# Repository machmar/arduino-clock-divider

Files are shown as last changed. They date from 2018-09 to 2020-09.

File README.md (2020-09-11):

# arduino-clock-divider
A clock divider that uses a arduino. It divides by 1; 2; 3; 4; 5; 6; 7; 8; 9 and 10.
```
Animations: (only some versions have this feature - the 1.1.1 and 1.4.1 dont have it for sure and Im not sure about the other versions)
       1.Activate them by unplugging the clock source.
       2.Use the divide by 10 as a clock input for animations.
       3.To select animations, Send a trigger to the divide by 9 pin.
       4.All of the animations are displayed on the divide by 1 to 8 leds
       5.Even thought it is displaying animations, it is still sending gates.
       6.To get back to dividing, just plug the clock jack back in.
```
THIS DIVIDER WILL NOT WORK WITH STEREO CABLES, as it relies on the fact that the mono jack shorts the second terminal of the stereo jack to ground. So If you want to make it work with stereo cables, than you have to connect the second contact to ground on the other side of the cable.

TO MAKE THIS WORK WITH STEREO CABLES, you just need to connect pin A0 to ground. That way the arduino will think you have a jack connected all the time, thus not deploing any animations at all. A optional thing you can do is to add a switch to the A0 that swithecs between 5 and 0 Volts.

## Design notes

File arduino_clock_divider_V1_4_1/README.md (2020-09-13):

So here it is. Im actually going throught my modules and fixing them.

This update adds new functionality while still keeping some of the old stuff. 
As in previous versions, plug a cable into the input to select Division mode. Leave the socket empty to select logic mode.
```
Division mode can be further adjusted with the expander (NOT TESTED WITH THIS VERSION) or the jumpers on the back.
Jumpers: 
  prime - 
      unconnected - the module divides by 1, 2, 3, 4, 5, 6, 7, 8, 9, 10
      connected   - the module divides by 1, 2, 3, 5, 7, 11, 13, 17, 19, 23
  serial - !NEVER CONNECT TOGETHER!
  edge - 
      unconnected - the module reacts both to the falling and rising edge of the clock input
      connected   - the module reacts to only the rising edge of the clock input
  g/t -
      unconnected - the module will output a gate signal    - once the division number is reached, 
                    the output state will invert
      connected   - the module will output a trigger signal - once the division number is reached, 
                    the output state will be set to high to a small ammount of time, after which 
                    it will be set back to low
  rst/10 - 
      unconnected - the module will use its "divide by 10" output as a standard output
      connected   - the module will use its "divide by 10" output as a trigger input - when this 
                    output recievs a high signal, it will reset all division counters and set 
                    all outputs to low
  leds - 
      unconnected - the LEDs behind the panel will not be refreshed and thus the module will run faster
      connected   - the LEDs behind the panel will be refreshed and thus the module will run slower but look better
      
Logic mode can not be adjusted with any jumpers - those are exclusive for division mode
  In logic mode, the outputs 1, 2, 9, 10 become inputs and the outputs 3, 4, 5, 6, 7, 8 become 
  outputs of logic operations controlled by the four inputs.
  
  In the code the inputs 1 and 2 are called A and B.
  The output 3 is "A & B" or in other words "both A and B have to be high for the output to be high".
  The output 4 is "A | B" or in other words "either A or B have to be high for the output to be high".
  The output 5 is "A ^ B" or in other words "exclusively only A or only B have to be high for the output to be high".
  
  In the code the inputs 9 and 10 are called C and D.
  The output 3 is "C & D" or in other words "both C and D have to be high for the output to be high".
  The output 4 is "C | D" or in other words "either C or D have to be high for the output to be high".
  The output 5 is "C ^ D" or in other words "exclusively only C or only D have to be high for the output to be high".
  
The swÿtches expander replaces the jumpers on the back with physical switches while also adding one aditional feature. 
  prime - 
      right - the module divides by 1, 2, 3, 4, 5, 6, 7, 8, 9, 10
      left  - the module divides by 1, 2, 3, 5, 7, 11, 13, 17, 19, 23
  edge - 
      right - the module reacts both to the falling and rising edge of the clock input
      let  - the module reacts to only the rising edge of the clock input
  g/t -
      right - the module will output a gate signal    - once the division number is reached, 
              the output state will invert
      left  - the module will output a trigger signal - once the division number is reached, 
              the output state will be set to high to a small ammount of time, after which 
              it will be set back to low
  rst/10 - 
      right - the module will use its "divide by 10" output as a standard output
      left  - the module will use its "divide by 10" output as a trigger input - when this 
              output recievs a high signal, it will reset all division counters and set 
              all outputs to low
  leds - 
      right - the LEDs behind the panel will be refreshed and thus the module will run slower but look better
      left  - the LEDs behind the panel will not be refreshed and thus the module will run faster
  potentiometer - 
    when trigger output is enabled, the trigger lenght can be adjusted from 0 to 200 milliseconds.
    !NOTE! When the potentiometer is set fully to left, it is possible for the gate mode to be 
    activated. This is a hardware design flaw that cant be fixed from software.
  ```

Yeah and thats about it really. I have to say this is a lot of text. It is just explained as clearly as I could. Also this is all written as a code so the dumb GitHub auto formatting doesnt ruin it.

Hope your build comes together well, Marek Mach

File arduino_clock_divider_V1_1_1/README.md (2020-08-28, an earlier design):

So Im going throught broken and bad modules of mine. I just wrote this code in like 4 hours from scratch so the clock divider runs better and has cooler animations.

This code WORKS ONLY WITH the .png schematic and NOT the EAGLE files.

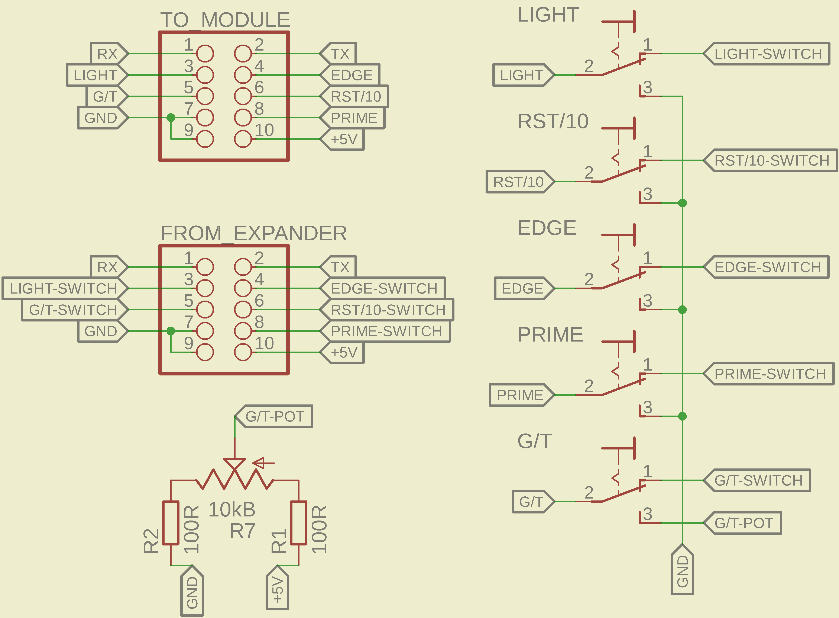
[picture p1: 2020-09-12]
hardware/swÿtches rev1.0/swÿtches expander schematic.png

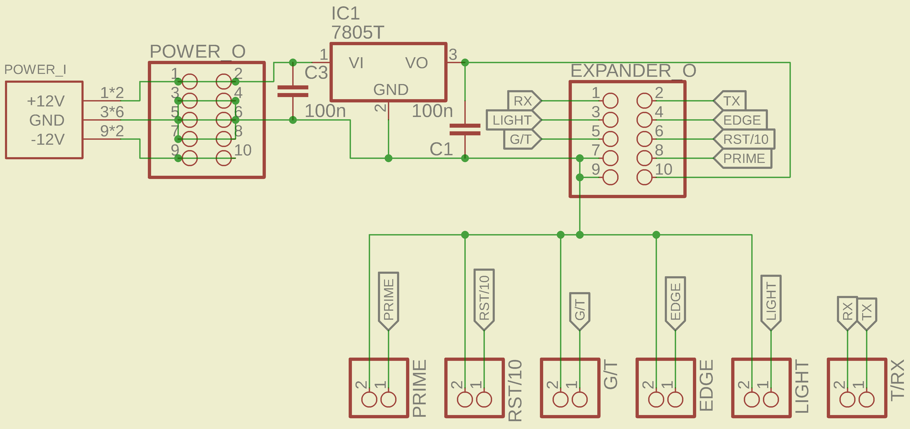
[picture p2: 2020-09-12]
hardware/expander board rev1.1/expander board schematic.png

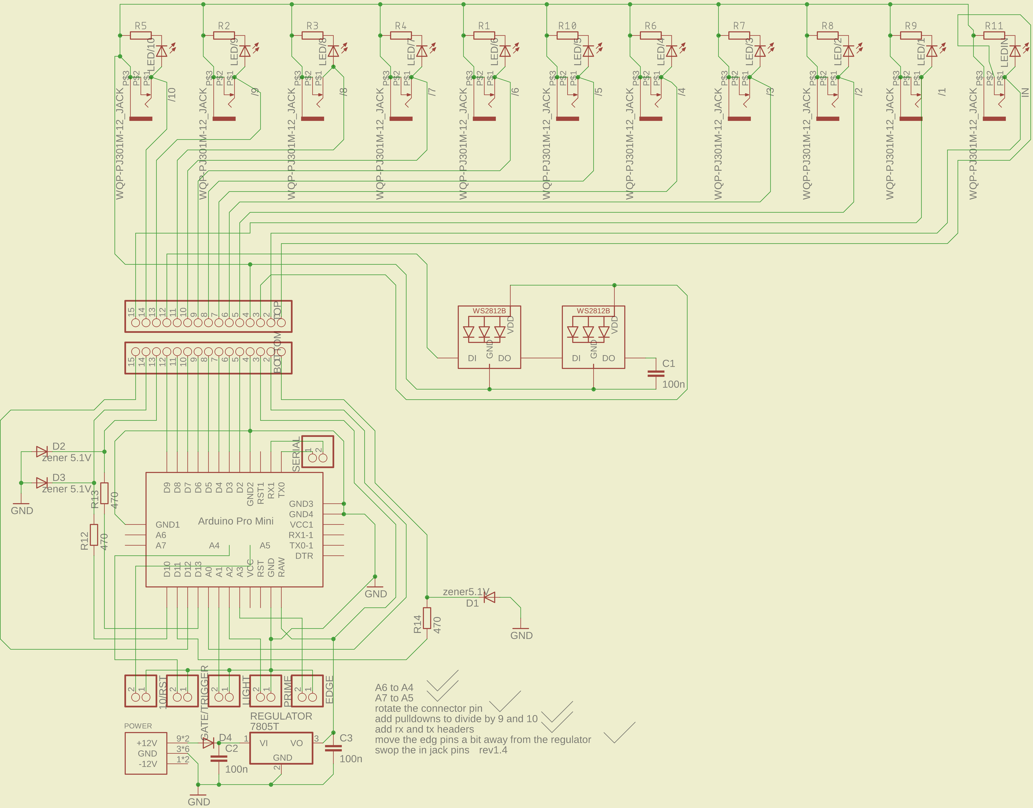
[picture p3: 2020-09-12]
hardware/arduino clock divider rev1.4/arduino clock divider schematic.png

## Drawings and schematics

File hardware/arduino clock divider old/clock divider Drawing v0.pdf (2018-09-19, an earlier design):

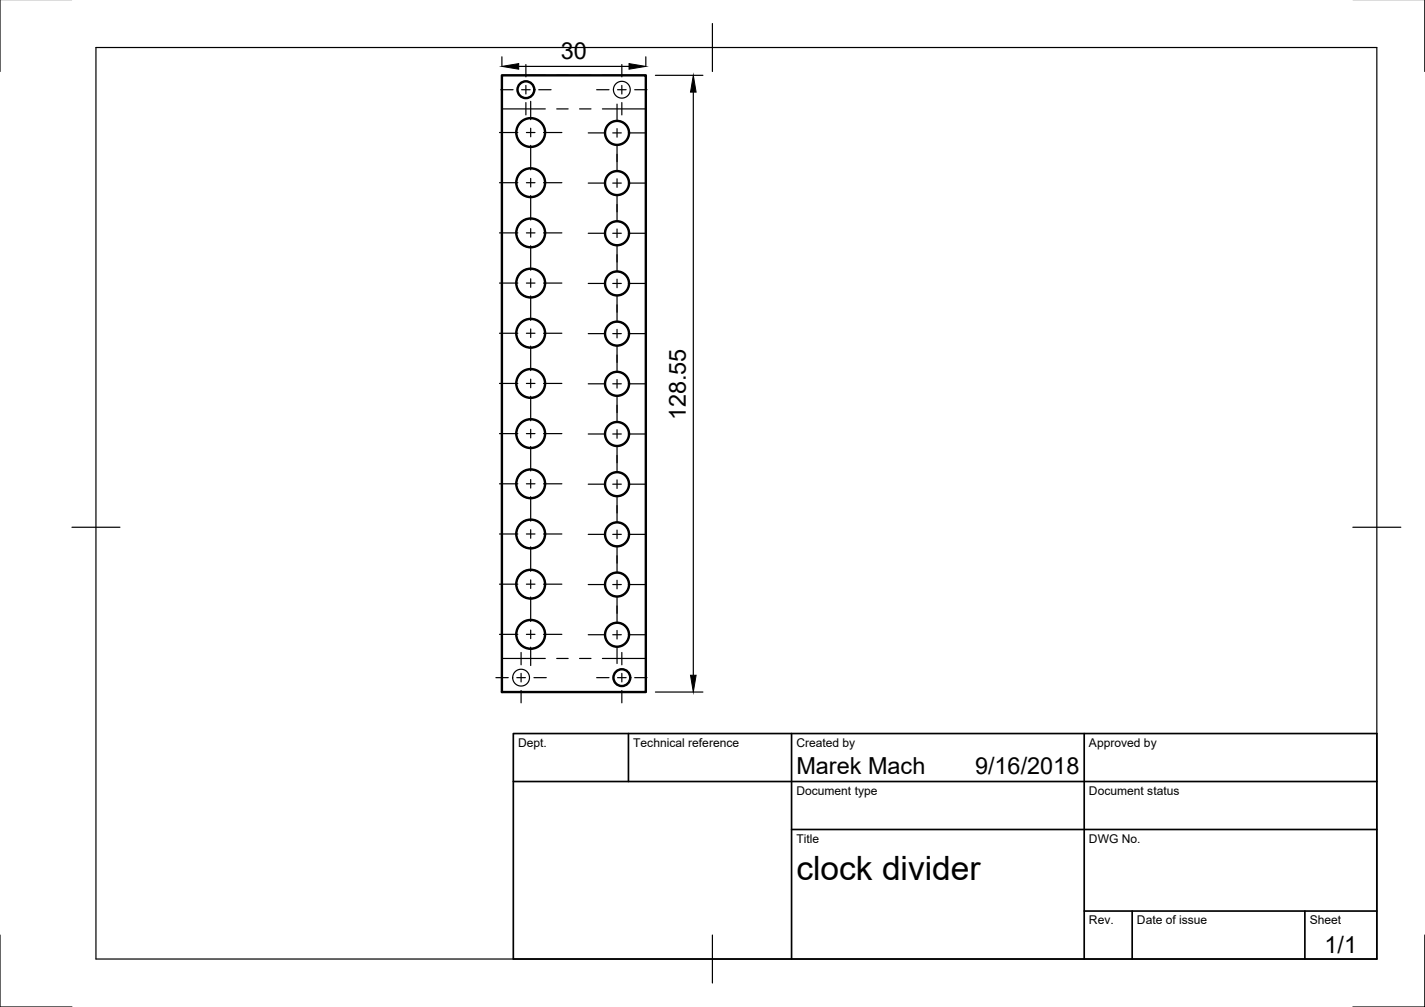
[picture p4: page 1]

Dept. | Technical reference | Created by Marek Mach 9/16/2018 | Approved by

Document type | Document status

Title clock divider | DWG No.

Rev. | Date of issue | Sheet 1/1

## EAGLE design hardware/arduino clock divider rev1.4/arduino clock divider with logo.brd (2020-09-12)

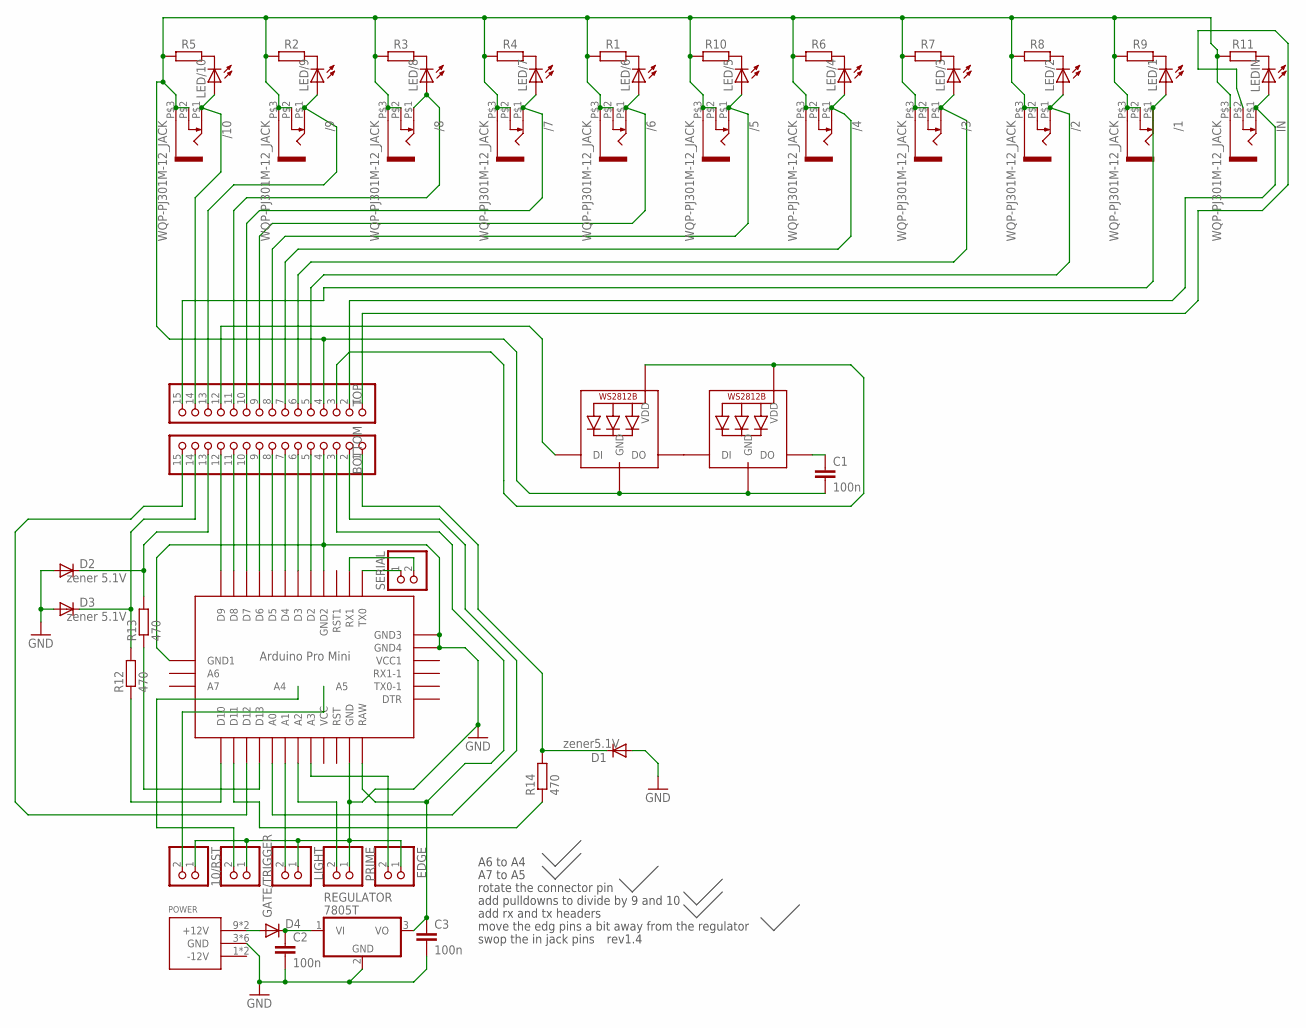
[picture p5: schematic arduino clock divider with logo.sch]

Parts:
10/RST: PINHD-1X2; 1X02
/1, /2, /3, /4, /5, /6, /7, /8, /9, /10: WQP-PJ301M-12_JACK
BOTTOM: PINHD-1X15-CB; 1X15-CB3D
C1, C2, C3: 100n; C025-025X050
D1: zener5.1V; DO35-10
D2, D3: zener 5.1V; DO35-10
D4: BAV21; DO35-10
EDGE: PINHD-1X2; 1X02
GATE/TRIGGER: PINHD-1X2; 1X02
IN: WQP-PJ301M-12_JACK
LED/1, LED/2, LED/3, LED/4, LED/5, LED/6, LED/7, LED/8, LED/9, LED/10: LED3MM
LEDIN: LED3MM
LIGHT: PINHD-1X2; 1X02
NEOPIX1, NEOPIX2: WS2812B5050; WS2812B
POWER: POWER_SIMPLE10; POWER_10
PRIME: PINHD-1X2; 1X02
R1, R2, R3, R4, R5, R6, R7, R8, R9, R10: 1k; 0204V
R11: 330; 0204V
R12, R13, R14: 470; 0204/7
REGULATOR: 7805T; TO220H
SERIAL: PINHD-1X2; 1X02
TOP: PINHD-1X15-CB; 1X15-CB3D
U$1: ABK-PRO-MINI-SMD

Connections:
GND: 10/RST.1, BOTTOM.4, C2.2, C3.2, D1.A, D2.A, D3.A, EDGE.1, GATE/TRIGGER.1, LIGHT.1, POWER.3 (GND), POWER.4 (GND), POWER.5 (GND), POWER.6 (GND), POWER.7 (GND), POWER.8 (GND), PRIME.1, REGULATOR.2 (GND), U$1.GND, U$1.GND1, U$1.GND2, U$1.GND3, U$1.GND4
unnamed: /6.P$1 (2), LED/6.A, TOP.9
unnamed: LED/6.K (C), R1.2
unnamed: BOTTOM.13, D2.C, R13.2
unnamed: LED/9.K (C), R2.2
unnamed: /8.P$1 (2), LED/8.A, TOP.11
unnamed: LED/8.K (C), R3.2
unnamed: /5.P$1 (2), LED/5.A, TOP.8
unnamed: LED/7.K (C), R4.2
unnamed: BOTTOM.14, D3.C, R12.2
unnamed: LED/10.K (C), R5.2
unnamed: /4.P$1 (2), LED/4.A, TOP.7
unnamed: LED/4.K (C), R6.2
unnamed: /3.P$1 (2), LED/3.A, TOP.6
unnamed: LED/3.K (C), R7.2
unnamed: /2.P$1 (2), LED/2.A, TOP.5
unnamed: LED/2.K (C), R8.2
unnamed: D4.A, POWER.9 (+12V), POWER.10 (+12V)
unnamed: LED/1.K (C), R9.2
unnamed: C2.1, D4.C, REGULATOR.1 (VI)
unnamed: LED/5.K (C), R10.2
unnamed: R14.1, U$1.D11
unnamed: LEDIN.K (C), R11.2
unnamed: IN.P$2 (3), TOP.1
unnamed: NEOPIX1.4-DIN (DI), TOP.12
unnamed: /7.P$1 (2), LED/7.A, TOP.10
unnamed: NEOPIX1.2-DOUT (DO), NEOPIX2.4-DIN (DI)
unnamed: /10.P$1 (2), LED/10.A, TOP.14
unnamed: C1.1, NEOPIX2.2-DOUT (DO)
unnamed: /9.P$1 (2), LED/9.A, TOP.13
unnamed: NEOPIX1.1-VDD (VDD), NEOPIX2.1-VDD (VDD), TOP.3
unnamed: PRIME.2, U$1.A2
unnamed: BOTTOM.3, C3.1, REGULATOR.3 (VO), U$1.RAW
unnamed: BOTTOM.12, U$1.D9
unnamed: BOTTOM.11, U$1.D8
unnamed: BOTTOM.10, U$1.D7
unnamed: BOTTOM.9, U$1.D6
unnamed: BOTTOM.8, U$1.D5
unnamed: BOTTOM.7, U$1.D4
unnamed: BOTTOM.6, U$1.D3
unnamed: BOTTOM.5, U$1.D2
unnamed: R13.1, U$1.D13
unnamed: R12.1, U$1.D10
unnamed: IN.P$1 (2), LEDIN.A, TOP.2
unnamed: /1.P$1 (2), LED/1.A, TOP.15
unnamed: BOTTOM.1, D1.C, R14.2
unnamed: BOTTOM.15, U$1.D12
unnamed: LIGHT.2, U$1.A1
unnamed: BOTTOM.2, U$1.A0
unnamed: EDGE.2, U$1.A3
unnamed: 10/RST.2, U$1.A5
unnamed: GATE/TRIGGER.2, U$1.A4
unnamed: SERIAL.2, U$1.RX1
unnamed: SERIAL.1, U$1.TX0
TOPGND: /1.P$2 (3), /1.P$3 (1), /2.P$2 (3), /2.P$3 (1), /3.P$2 (3), /3.P$3 (1), /4.P$2 (3), /4.P$3 (1), /5.P$2 (3), /5.P$3 (1), /6.P$2 (3), /6.P$3 (1), /7.P$2 (3), /7.P$3 (1), /8.P$2 (3), /8.P$3 (1), /9.P$2 (3), /9.P$3 (1), /10.P$2 (3), /10.P$3 (1), C1.2, IN.P$3 (1), NEOPIX1.3-GND (GND), NEOPIX2.3-GND (GND), R1.1, R2.1, R3.1, R4.1, R5.1, R6.1, R7.1, R8.1, R9.1, R10.1, R11.1, TOP.4

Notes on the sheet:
A6 to A4
A7 to A5
rotate the connector pin
add pulldowns to divide by 9 and 10
add rx and tx headers
move the edg pins a bit away from the regulator
swop the in jack pins
rev1.4

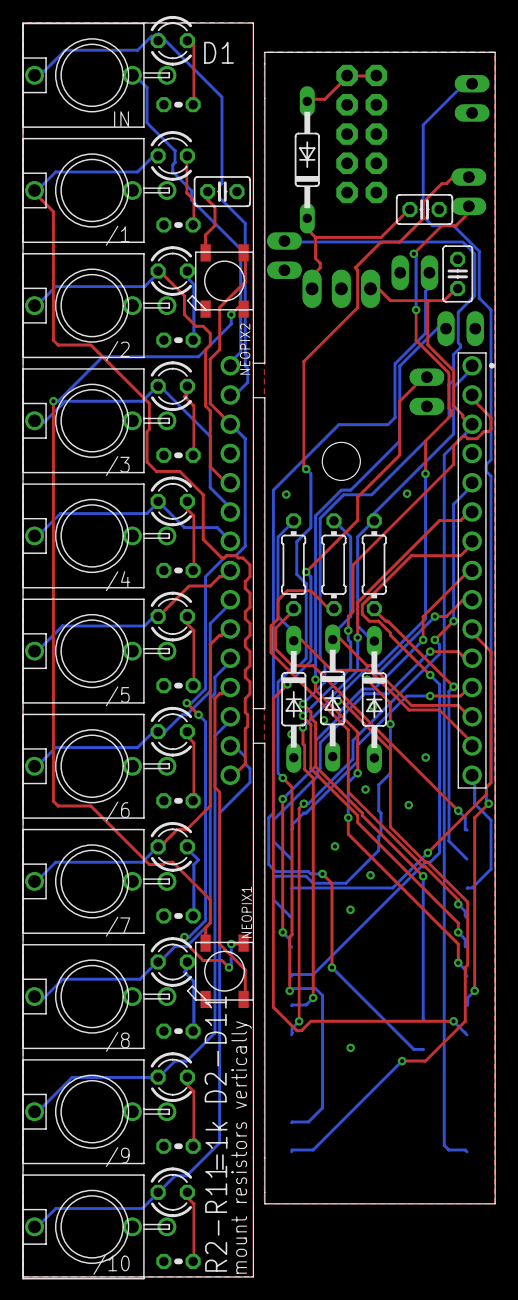
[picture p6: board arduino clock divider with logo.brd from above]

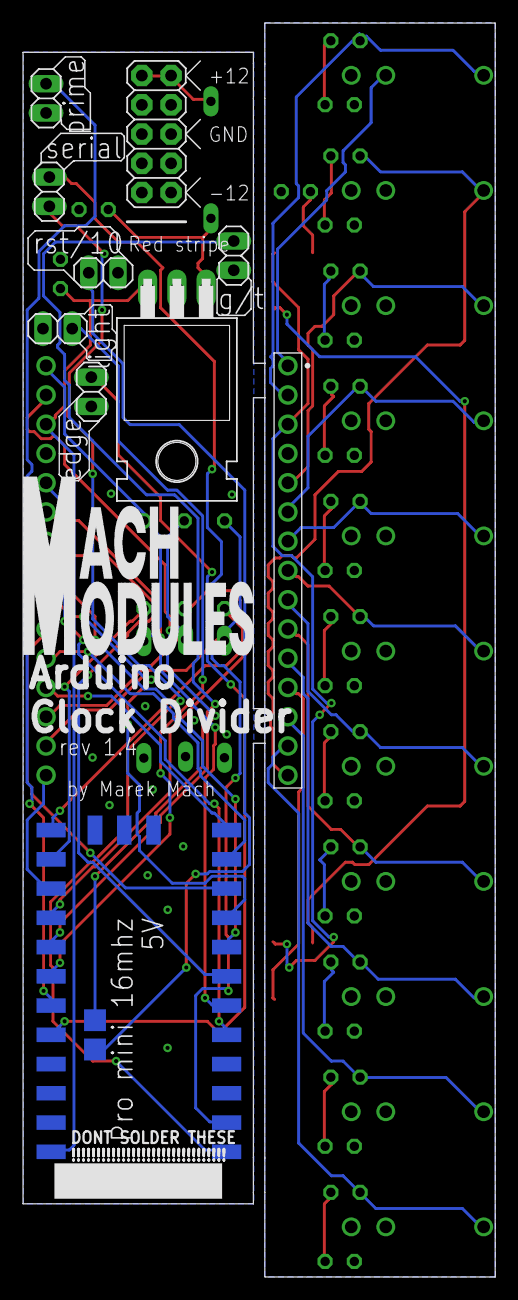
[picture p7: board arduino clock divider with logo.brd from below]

Board: 2 copper layers, 41.0 x 108.9 mm, 56 parts (10 on the bottom side), 55 nets.

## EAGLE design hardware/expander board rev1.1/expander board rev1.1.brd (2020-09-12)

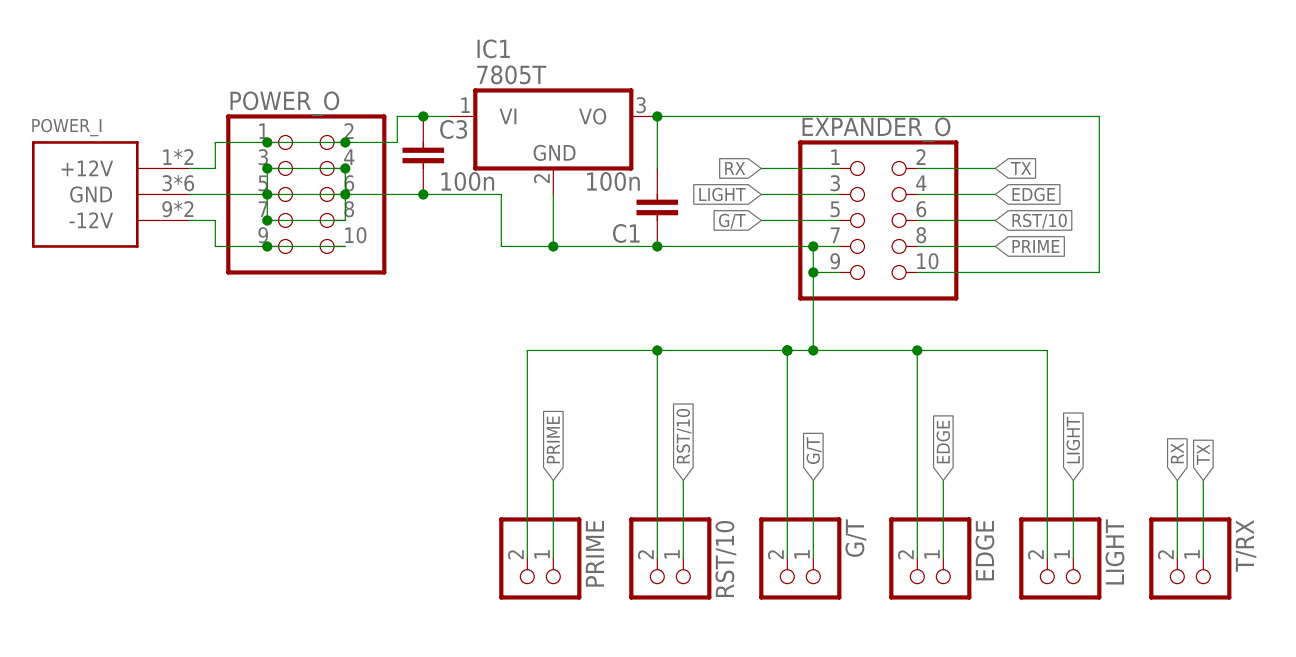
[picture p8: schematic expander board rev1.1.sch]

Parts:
C1, C3: 100n; C025-025X050
EDGE: PINHD-1X2; 1X02
EXPANDER_O: PINHD-2X5; 2X05
G/T: PINHD-1X2; 1X02
IC1: 7805T; TO220H
LIGHT: PINHD-1X2; 1X02
POWER_I: POWER_SIMPLE; POWER_10_NSTRIPE
POWER_O: PINHD-2X5; 2X05
PRIME: PINHD-1X2; 1X02
RST/10: PINHD-1X2; 1X02
T/RX: PINHD-1X2; 1X02

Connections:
+5V: C1.2, EXPANDER_O.10, IC1.3 (VO)
+12V: C3.1, IC1.1 (VI), POWER_I.1 (+12V), POWER_I.2 (+12V), POWER_O.1, POWER_O.2
-12V: POWER_I.9 (-12V), POWER_I.10 (-12V), POWER_O.9, POWER_O.10
EDGE: EDGE.1, EXPANDER_O.4
G/T: EXPANDER_O.5, G/T.1
GND: C1.1, C3.2, EDGE.2, EXPANDER_O.7, EXPANDER_O.9, G/T.2, IC1.2 (GND), LIGHT.2, POWER_I.3 (GND), POWER_I.4 (GND), POWER_I.5 (GND), POWER_I.6 (GND), POWER_I.7 (GND), POWER_I.8 (GND), POWER_O.3, POWER_O.4, POWER_O.5, POWER_O.6, POWER_O.7, POWER_O.8, PRIME.2, RST/10.2
LIGHT: EXPANDER_O.3, LIGHT.1
PRIME: EXPANDER_O.8, PRIME.1
RST/10: EXPANDER_O.6, RST/10.1
RX: EXPANDER_O.1, T/RX.2
TX: EXPANDER_O.2, T/RX.1

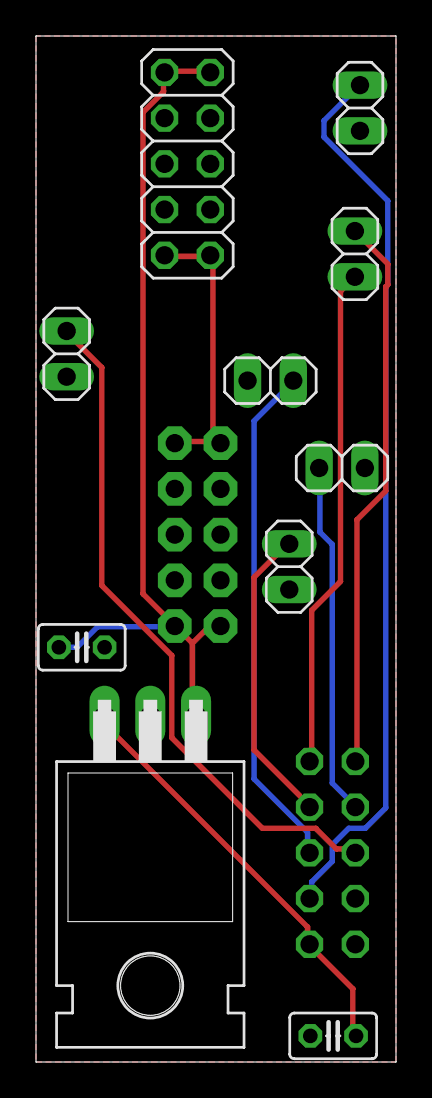
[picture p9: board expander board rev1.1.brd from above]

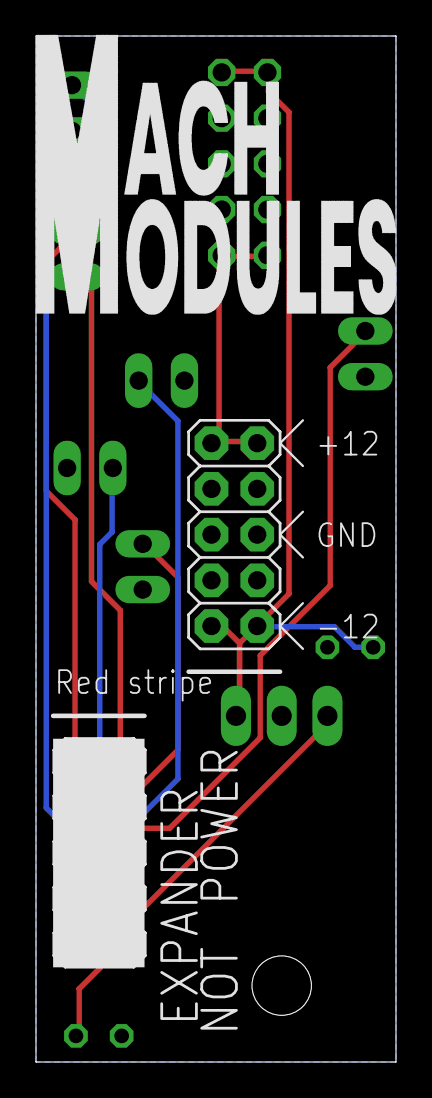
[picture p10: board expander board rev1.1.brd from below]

Board: 2 copper layers, 20.0 x 57.0 mm, 12 parts (2 on the bottom side), 11 nets.

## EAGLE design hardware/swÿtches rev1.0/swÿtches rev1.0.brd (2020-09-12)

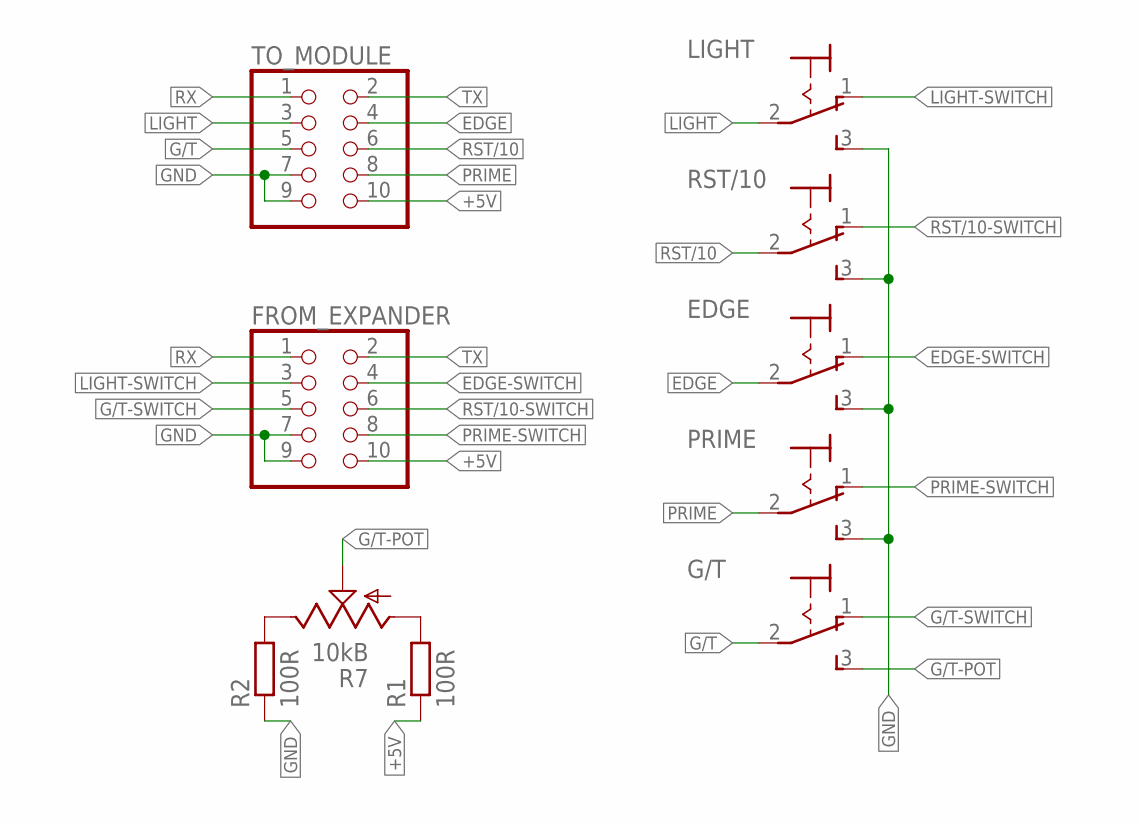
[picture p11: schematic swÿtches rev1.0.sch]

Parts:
EDGE: 320-916320-916BIG; 320-916MY
FROM_EXPANDER: PINHD-2X5; 2X05
G/T: 320-916320-916BIG; 320-916MY
LIGHT: 320-916320-916BIG; 320-916MY
PRIME: 320-916320-916BIG; 320-916MY
R1, R2: 100R; 0204/7
R7: 10kB; ALPS_POT_VERTICAL_PS
RST/10: 320-916320-916BIG; 320-916MY
TO_MODULE: PINHD-2X5; 2X05

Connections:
+5V: FROM_EXPANDER.10, R1.1, TO_MODULE.10
EDGE: EDGE.2, TO_MODULE.4
EDGE-SWITCH: EDGE.1 (O), FROM_EXPANDER.4
G/T: G/T.2, TO_MODULE.5
G/T-POT: G/T.3 (S), R7.P$2 (S)
G/T-SWITCH: FROM_EXPANDER.5, G/T.1 (O)
GND: EDGE.3 (S), FROM_EXPANDER.7, FROM_EXPANDER.9, LIGHT.3 (S), PRIME.3 (S), R2.1, RST/10.3 (S), TO_MODULE.7, TO_MODULE.9
LIGHT: LIGHT.2, TO_MODULE.3
LIGHT-SWITCH: FROM_EXPANDER.3, LIGHT.1 (O)
unnamed: R2.2, R7.P$1 (E)
unnamed: R1.2, R7.P$3 (A)
PRIME: PRIME.2, TO_MODULE.8
PRIME-SWITCH: FROM_EXPANDER.8, PRIME.1 (O)
RST/10: RST/10.2, TO_MODULE.6
RST/10-SWITCH: FROM_EXPANDER.6, RST/10.1 (O)
RX: FROM_EXPANDER.1, TO_MODULE.1
TX: FROM_EXPANDER.2, TO_MODULE.2

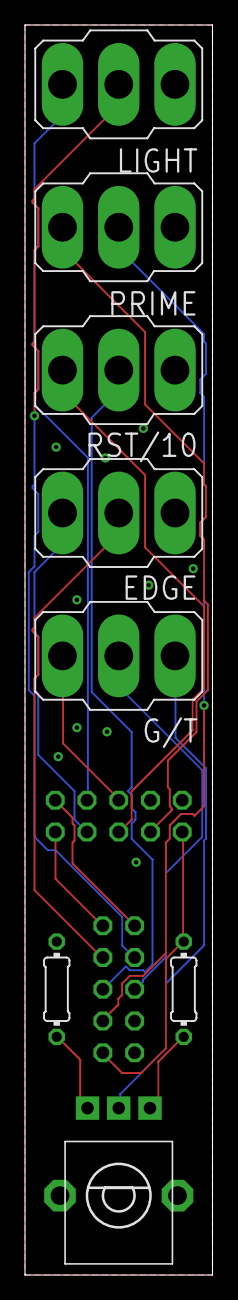
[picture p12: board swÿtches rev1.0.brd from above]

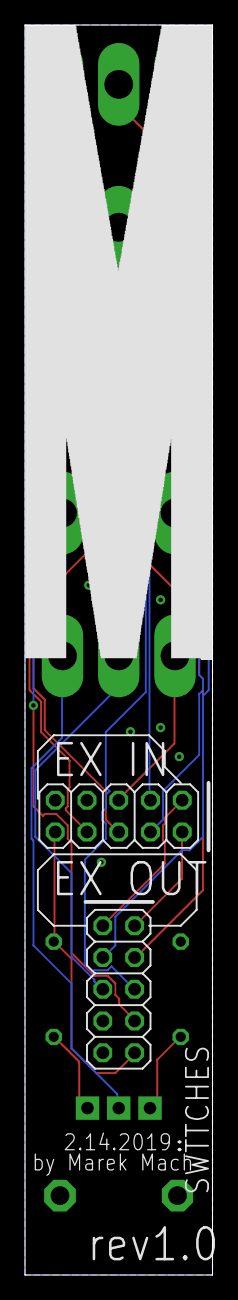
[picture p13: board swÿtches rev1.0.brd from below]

Board: 2 copper layers, 15.0 x 100.0 mm, 10 parts (2 on the bottom side), 17 nets.

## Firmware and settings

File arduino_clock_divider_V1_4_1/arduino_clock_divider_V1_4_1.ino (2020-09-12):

#include <FastLED.h>

//I want to rewrite the whole code for this new 4hp version too
//!WARNING! The expander should be working but Im not sure as my expander broke. !EDIT! The expander works fine.

const static uint8_t outJack[] = {12, 2, 3, 4, 5, 6, 7, 8, 13, 10};
#define inJack 11
#define inDetect 14
#define lightS 15
#define primeS 16
#define edgeS 17
#define gateTriggerS 18
#define reset10S 19

#define triggerLenght 10

//#define SerialDebug //uncomment this #define to enable Serial DEBUG.
//The Baud rate is 1000000 - it will work with both 8 and 16 MHz based arduinos.

bool lightPrev;
bool primePrev;
bool edgePrev;
bool reset10Prev;
uint8_t pixelHue[2];
uint32_t ledPMill;
bool inDetectPrev;
bool inPrev;
uint8_t counter[11];
bool gate2TriggerClockFlag;
uint32_t gate2TriggerPMill;
bool outputState[11];
bool gate2TriggerTimerRunning;
uint32_t logicLedPMill;

CRGB led[2];

void setup() {
  for (uint8_t i = 0; i < 10; i++) pinMode(outJack[i], OUTPUT);
  for (uint8_t i = 0; i < 10; i++) digitalWrite(outJack[i], 0);
  pinMode(inDetect, INPUT_PULLUP);
  pinMode (lightS, INPUT_PULLUP);
  pinMode (primeS, INPUT_PULLUP);
  pinMode (edgeS, INPUT_PULLUP);
  pinMode (gateTriggerS, INPUT_PULLUP);
  pinMode (reset10S, INPUT_PULLUP);

  FastLED.addLeds<NEOPIXEL, 9>(led, 2);

  led[0] = 0xff0000;
  led[1] = 0x5500ff;
  FastLED.show();

  #ifdef SerialDebug
  Serial.begin(1000000);
  Serial.println("Rudimentary DEBUG connection established. Starting DEBUG.");
  Serial.println("!WARNING! The module will run significantly slower with this DEBUG running.");
  Serial.println();
  #endif

  //IN-jack-and-other-configuration-BEGIN
  inDetectPrev = digitalRead(inDetect);
  if (!digitalRead(inDetect)) {
    pinMode(inJack, INPUT_PULLUP);
    pinMode(outJack[0], OUTPUT);
    pinMode(outJack[1], OUTPUT);
    pinMode(outJack[8], OUTPUT);
    pinMode(outJack[9], digitalRead(reset10S));
    #ifdef SerialDebug
    Serial.println("Device starting with division mode enabled.");
    #endif
  }
  else {
    pinMode(inJack, INPUT);
    pinMode(outJack[0], INPUT);
    pinMode(outJack[1], INPUT);
    pinMode(outJack[8], INPUT);
    pinMode(outJack[9], INPUT);
    #ifdef SerialDebug
    Serial.println("Device starting with logic mode enabled.");
    #endif
  }
  //IN-jack-and-other-configuration-END
}

void refreshLeds(uint8_t brightness, uint8_t fps) {
  uint32_t CMill = millis();
  if (CMill - ledPMill >= 1000 / fps) {
    ledPMill = CMill;
    FastLED.setBrightness(brightness);
    FastLED.show();
    #ifdef SerialDebug
    Serial.println("LEDs refreshed");
    #endif
  }
}

void divisionCore(uint8_t divisions[], bool edge, bool disable10) {
  bool inState = digitalRead(inJack);
  if (inState != inPrev) { //INput jack state change detection
    inPrev = inState;
    #ifdef SerialDebug
    Serial.print("Clock impulse detected. The current state is: ");
    Serial.println(inState);
    #endif
    if (edge || !edge && inState) {
      for (uint8_t i = 0; i < 10; i++) { //increments the counters
        counter[i]++;
      }
      gate2TriggerClockFlag = 1;
    }

    for (uint8_t i = 0; i < 10 - disable10; i++) { //check if the counter is high enough to change the ouptut state
      if (divisions[i] == 1) {
        outputState[i] = inState;
        counter[i] = 0;
      }
      else if (counter[i] >= divisions[i]) {
        outputState[i] = !outputState[i];
        counter[i] = 0;
      }
    }
    if (disable10) digitalWrite(outJack[9], 0);
    led[0] = CHSV(pixelHue[0]++, 255, 255); //this led just updates its hue every time this loops
    led[1] = CHSV(pixelHue[1] -= 2, 255, 255); //this led does the same as the other one just three times faster
  }
}

void gate2Trigger(uint16_t trigLenght) {
  uint32_t CMill = millis();

  if (gate2TriggerClockFlag) {
    for (uint8_t i = 0; i < 10; i++) {
      digitalWrite(outJack[i], outputState[i]);
      if (outputState[i]) {
        outputState[i] = 0;
        counter[i] = 0;
      }
    }
    gate2TriggerPMill = CMill;
    gate2TriggerClockFlag = 0;
    gate2TriggerTimerRunning = 1;
    #ifdef SerialDebug
    Serial.println("Outs set to theier state.");
    #endif
  }

  if (CMill - gate2TriggerPMill >= trigLenght && gate2TriggerTimerRunning) {
    for (uint8_t i = 0; i < 10; i++) digitalWrite(outJack[i], 0);
    gate2TriggerTimerRunning = 0;
    #ifdef SerialDebug
    Serial.println("Outs set to logical 0.");
    #endif
  }
}

void gate2Jack() {
  for (uint8_t i = 0; i < 10; i++) digitalWrite(outJack[i], outputState[i]);
}

void dividing() {
  bool lightState = digitalRead(lightS);
  bool primeState = digitalRead(primeS);
  bool edgeState = digitalRead(edgeS);
  uint16_t gateTriggerState = analogRead(gateTriggerS);
  bool reset10State = digitalRead(reset10S);

  if (!lightState) refreshLeds(255, 15);

  uint8_t standardDividing[] = {1, 2, 3, 4, 5, 6, 7, 8, 9, 10};
  uint8_t primeDividing[] = {1, 2, 3, 5, 7, 11, 13, 17, 19, 23};
  if (primeState) divisionCore(standardDividing, edgeState, !reset10State);
  else divisionCore(primeDividing, edgeState, !reset10State);

  if (gateTriggerState > 980) gate2Jack();
  else if (gateTriggerState > 20) gate2Trigger(map(gateTriggerState, 25, 975, 200, 0));
  else gate2Trigger(triggerLenght);

  if (reset10State != reset10Prev) {
    reset10Prev = reset10State;
    pinMode(outJack[9], reset10State);
  }
  if (!reset10State) {
    digitalWrite(outJack[9], 0);
    if (digitalRead(outJack[9])) {
    for (uint8_t i = 0; i < 9; i++) {
        outputState[i] = 0;
        counter[i] = 0;
      }
    }
  }
}

void logic() {
  bool AState = digitalRead(outJack[0]);
  bool BState = digitalRead(outJack[1]);
  bool CState = digitalRead(outJack[8]);
  bool DState = digitalRead(outJack[9]);

  digitalWrite(outJack[2], AState & BState);
  digitalWrite(outJack[3], AState | BState);
  digitalWrite(outJack[4], AState ^ BState);
  digitalWrite(outJack[5], CState & DState);
  digitalWrite(outJack[6], CState | DState);
  digitalWrite(outJack[7], CState ^ DState);

  if (millis() - logicLedPMill >= 50) {
    logicLedPMill = millis();
    led[0] = CHSV(pixelHue[0]++, 255, 255); //this led just updates its hue every time this loops
    led[1] = CHSV(pixelHue[1] -= 2, 255, 255); //this led does the same as the other one just three times faster
  }

  if (!digitalRead(lightS)) refreshLeds(255, 20);
}

void loop() {
  bool inDetectState = digitalRead(inDetect);
  if (inDetectState != inDetectPrev) { //change INput direction when the jack plugs in or unplugs
    inDetectPrev = inDetectState;
    for (uint8_t i = 0; i < 10; i++) digitalWrite(outJack[i], 0);
    if (!inDetectState) {
      pinMode(inJack, INPUT_PULLUP);
      pinMode(outJack[0], OUTPUT);
      pinMode(outJack[1], OUTPUT);
      pinMode(outJack[8], OUTPUT);
      pinMode(outJack[9], digitalRead(reset10S));
      #ifdef SerialDebug
      Serial.println("IN jack plugged in");
      #endif
    }
    else {
      pinMode(inJack, INPUT);
      pinMode(outJack[0], INPUT);
      pinMode(outJack[1], INPUT);
      pinMode(outJack[8], INPUT);
      pinMode(outJack[9], INPUT);
      #ifdef SerialDebug
      Serial.println("IN jack unplugged");
      #endif
    }
  }
  if (inDetectState) logic();
  else dividing();
}

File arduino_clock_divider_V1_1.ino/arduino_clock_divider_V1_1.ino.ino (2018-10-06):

int out1 = 11;
int out2 = 2;
int out3 = 3;
int out4 = 4;
int out5 = 5;
int out6 = 6;
int out7 = 7;
int out8 = 8;
int out9 = 9;
int out10 = 10;
int out1Var = 0;
int out2Var = 0;
int out3Var = 0;
int out4Var = 0;
int out5Var = 0;
int out6Var = 0;
int out7Var = 0;
int out8Var = 0;
int out9Var = 0;
int out10Var = 0;
int aniVar = 0;
int aniSelect = 0;
int in = 12;
int inDetect = 14;
int inDetectVar = 1;
int inState = 0;
bool out9State = 0;
bool out9Prev = 1;
bool out10State = 0;
bool out10Prev = 1;
bool inPrev = 1;


void setup() {
  pinMode (out1, OUTPUT);
  pinMode (out2, OUTPUT);
  pinMode (out3, OUTPUT);
  pinMode (out4, OUTPUT);
  pinMode (out5, OUTPUT);
  pinMode (out6, OUTPUT);
  pinMode (out7, OUTPUT);
  pinMode (out8, OUTPUT);
  pinMode (in, INPUT_PULLUP);
  pinMode (inDetect, INPUT_PULLUP);
  Serial.begin(2000000);
}

void reading() {
  if (digitalRead(inDetect) == 1) {
    out9State = digitalRead(out9);
    if (out9State == 0 && out9Prev == 0) {
      out9Prev = 1;
    }
    if (out9State == 1 && out9Prev == 1) {
      aniSelect++;
      out9Prev = 0;
    }
    out10State = digitalRead(out10);
    if (out10State == 0 && out10Prev == 0) {
      out10Prev = 1;
    }
    if (out10State == 1 && out10Prev == 1) {
      aniVar++;
      out10Prev = 0;
    }
}
  
  if (digitalRead(inDetect) == 0) {
    inState = digitalRead(in);
    if (inState == 0 && inPrev == 0) {
    digitalWrite(out1, 0);
    out1Var++;
    out2Var++;
    out3Var++;
    out4Var++;
    out5Var++;
    out6Var++;
    out7Var++;
    out8Var++;
    out9Var++;
    out10Var++;
    inPrev = 1;
  }
  if (inState == 1 && inPrev == 1) {
    digitalWrite(out1, 1);
    out1Var++;
    out2Var++;
    out3Var++;
    out4Var++;
    out5Var++;
    out6Var++;
    out7Var++;
    out8Var++;
    out9Var++;
    out10Var++;
    inPrev = 0;
  }
  if (out1Var == 2) out1Var = 0;
  if (out2Var == 4) out2Var = 0;
  if (out3Var == 6) out3Var = 0;
  if (out4Var == 8) out4Var = 0;
  if (out5Var == 10) out5Var = 0;
  if (out6Var == 12) out6Var = 0;
  if (out7Var == 14) out7Var = 0;
  if (out8Var == 16) out8Var = 0;
  if (out9Var == 18) out9Var = 0;
  if (out10Var == 20) out10Var = 0;
  }

}

void loop() {
  inDetectVar = digitalRead(inDetect);
  if (inDetectVar == 1) {
  pinMode (out9, INPUT);
  pinMode (out10, INPUT_PULLUP);
    if (aniSelect == 0) {
      if (aniVar == 0) digitalWrite (out1, 1); 
      if (aniVar == 1) digitalWrite (out2, 1); 
      if (aniVar == 2) digitalWrite (out3, 1); 
      if (aniVar == 3) digitalWrite (out4, 1); 
      if (aniVar == 4) digitalWrite (out5, 1); 
      if (aniVar == 5) digitalWrite (out6, 1); 
      if (aniVar == 6) digitalWrite (out7, 1); 
      if (aniVar == 7) digitalWrite (out8, 1); 
      if (aniVar == 8) digitalWrite (out1, 0); 
      if (aniVar == 9) digitalWrite (out2, 0); 
      if (aniVar == 10) digitalWrite (out3, 0); 
      if (aniVar == 11) digitalWrite (out4, 0); 
      if (aniVar == 12) digitalWrite (out5, 0); 
      if (aniVar == 13) digitalWrite (out6, 0); 
      if (aniVar == 14) digitalWrite (out7, 0); 
      if (aniVar == 15) digitalWrite (out8, 0); 
      if (aniVar >= 16) aniVar = 0;
  }
  if (aniSelect == 1) {
      if (aniVar == 0) {
        digitalWrite (out1, 1); 
      }
      if (aniVar == 1) {
        digitalWrite (out2, 1); 
      }
      if (aniVar == 2) {
        digitalWrite (out3, 1); 
      }
      if (aniVar == 3) {
        digitalWrite (out4, 1); 
      }
      if (aniVar == 4) {
        digitalWrite (out5, 1); 
      }
      if (aniVar == 5) {
        digitalWrite (out6, 1); 
      }
      if (aniVar == 6) {
        digitalWrite (out7, 1); 
      }
      if (aniVar == 7) {
        digitalWrite (out1, 0);
        digitalWrite (out8, 1); 
      }
      if (aniVar == 8) {
        digitalWrite (out2, 0); 
      }
      if (aniVar == 9) {
        digitalWrite (out3, 0); 
      }
      if (aniVar == 10) {
        digitalWrite (out4, 0); 
      }
      if (aniVar == 11) {
        digitalWrite (out5, 0); 
      }
      if (aniVar == 12) {
        digitalWrite (out6, 0); 
      }
      if (aniVar == 13) {
        digitalWrite (out7, 0); 
      }
      if (aniVar == 14) {
        digitalWrite (out8, 0); 
      }
      if (aniVar >= 15) aniVar = 0;
  }
  if (aniSelect == 2) {
      if (aniVar == 0) {
        digitalWrite (out1, 1); 
      }
      if (aniVar == 1) {
        digitalWrite (out2, 1); 
      }
      if (aniVar == 2) {
        digitalWrite (out3, 1); 
      }
      if (aniVar == 3) {
        digitalWrite (out4, 1); 
      }
      if (aniVar == 4) {
        digitalWrite (out5, 1); 
      }
      if (aniVar == 5) {
        digitalWrite (out6, 1); 
      }
      if (aniVar == 6) {
        digitalWrite (out1, 0);
        digitalWrite (out7, 1); 
      }
      if (aniVar == 7) {
        digitalWrite (out2, 0);
        digitalWrite (out8, 1); 
      }
      if (aniVar == 8) {
        digitalWrite (out1, 0); 
      }
      if (aniVar == 9) {
        digitalWrite (out2, 0); 
      }
      if (aniVar == 8) {
        digitalWrite (out3, 0); 
      }
      if (aniVar == 9) {
        digitalWrite (out4, 0); 
      }
      if (aniVar == 10) {
        digitalWrite (out5, 0); 
      }
      if (aniVar == 11) {
        digitalWrite (out6, 0); 
      }
      if (aniVar == 12) {
        digitalWrite (out7, 0); 
      }
      if (aniVar == 13) {
        digitalWrite (out8, 0); 
      }
      if (aniVar >= 14) aniVar = 0;
  }
  if (aniSelect == 3) {
      if (aniVar == 0) {
        digitalWrite (out1, 1); 
      }
      if (aniVar == 1) {
        digitalWrite (out2, 1); 
      }
      if (aniVar == 2) {
        digitalWrite (out3, 1); 
      }
      if (aniVar == 3) {
        digitalWrite (out4, 1); 
      }
      if (aniVar == 4) {
        digitalWrite (out5, 1); 
      }
      if (aniVar == 5) {
        digitalWrite (out1, 0);
        digitalWrite (out6, 1); 
      }
      if (aniVar == 6) {
        digitalWrite (out2, 0);
        digitalWrite (out7, 1); 
      }
      if (aniVar == 7) {
        digitalWrite (out3, 0);
        digitalWrite (out8, 1); 
      }
      if (aniVar == 8) {
        digitalWrite (out4, 0); 
      }
      if (aniVar == 9) {
        digitalWrite (out5, 0); 
      }
      if (aniVar == 10) {
        digitalWrite (out6, 0); 
      }
      if (aniVar == 11) {
        digitalWrite (out7, 0); 
      }
      if (aniVar == 12) {
        digitalWrite (out8, 0); 
      }
      if (aniVar >= 13) aniVar = 0;
  }
  if (aniSelect == 4) {
      if (aniVar == 0) {
        digitalWrite (out1, 1); 
      }
      if (aniVar == 1) {
        digitalWrite (out2, 1); 
      }
      if (aniVar == 2) {
        digitalWrite (out3, 1); 
      }
      if (aniVar == 3) {
        digitalWrite (out4, 1); 
      }
      if (aniVar == 4) {
        digitalWrite (out1, 0);
        digitalWrite (out5, 1); 
      }
      if (aniVar == 5) {
        digitalWrite (out2, 0);
        digitalWrite (out6, 1); 
      }
      if (aniVar == 6) {
        digitalWrite (out3, 0);
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

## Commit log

2018-10-06 A new update
    I have added animations.
    [arduino clock divider.sch]
2018-12-21 and the schematic changet a little bit
    [arduino clock divider.sch]
2019-07-30 added new hardware files
    [arduino clock divider with logo.brd, arduino clock divider with logo.sch]
2020-08-28 new code for the first design prototype
2020-09-12 added and fixed hardware designs
    [arduino clock divider with logo.brd, arduino clock divider with logo.sch, arduino clock divider.sch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]
2020-09-12 fixed a small boot bug
    [arduino_clock_divider_V1_4_1.ino]
2020-09-13 added LEDs description switch

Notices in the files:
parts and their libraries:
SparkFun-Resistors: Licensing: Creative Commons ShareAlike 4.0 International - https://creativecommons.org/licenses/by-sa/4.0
